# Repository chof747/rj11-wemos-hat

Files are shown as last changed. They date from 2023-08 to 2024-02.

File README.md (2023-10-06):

## rj11-wemos-hat
Stack-up board for the [wemos-mains-dev board](https://github.com/chof747/wemos-mains-dev) which includes 2 RJ11 connectors that can be connected via solder pads to the broken out pins of the wemos D1 mini on the main board.

The board has the form factor to be stacked up on the wemos mains dev board to enable mains powered wifi enabled 
microcontroller projects

### Elements

- 2 RJ11 Connectors
- Solder pads for all wemos pins (except 5V, 3V3 and GND)
- 2 1x2 connector pads exposing the data lines of the RJ11s
- 2 Jumpers to select the available 5V or 3V3 rail for the RJ11 connector
- A push button for the reset and a push button for the flash pin of the wemos D1 mini + pull-ups 
 
## Used Parts:

## Revision History:

- **v1.0**: Initial version (Produced: 19.08.2023; First Assembly: 06.10.2023)
- **v1.1**: Corrected RJ12 socket connector

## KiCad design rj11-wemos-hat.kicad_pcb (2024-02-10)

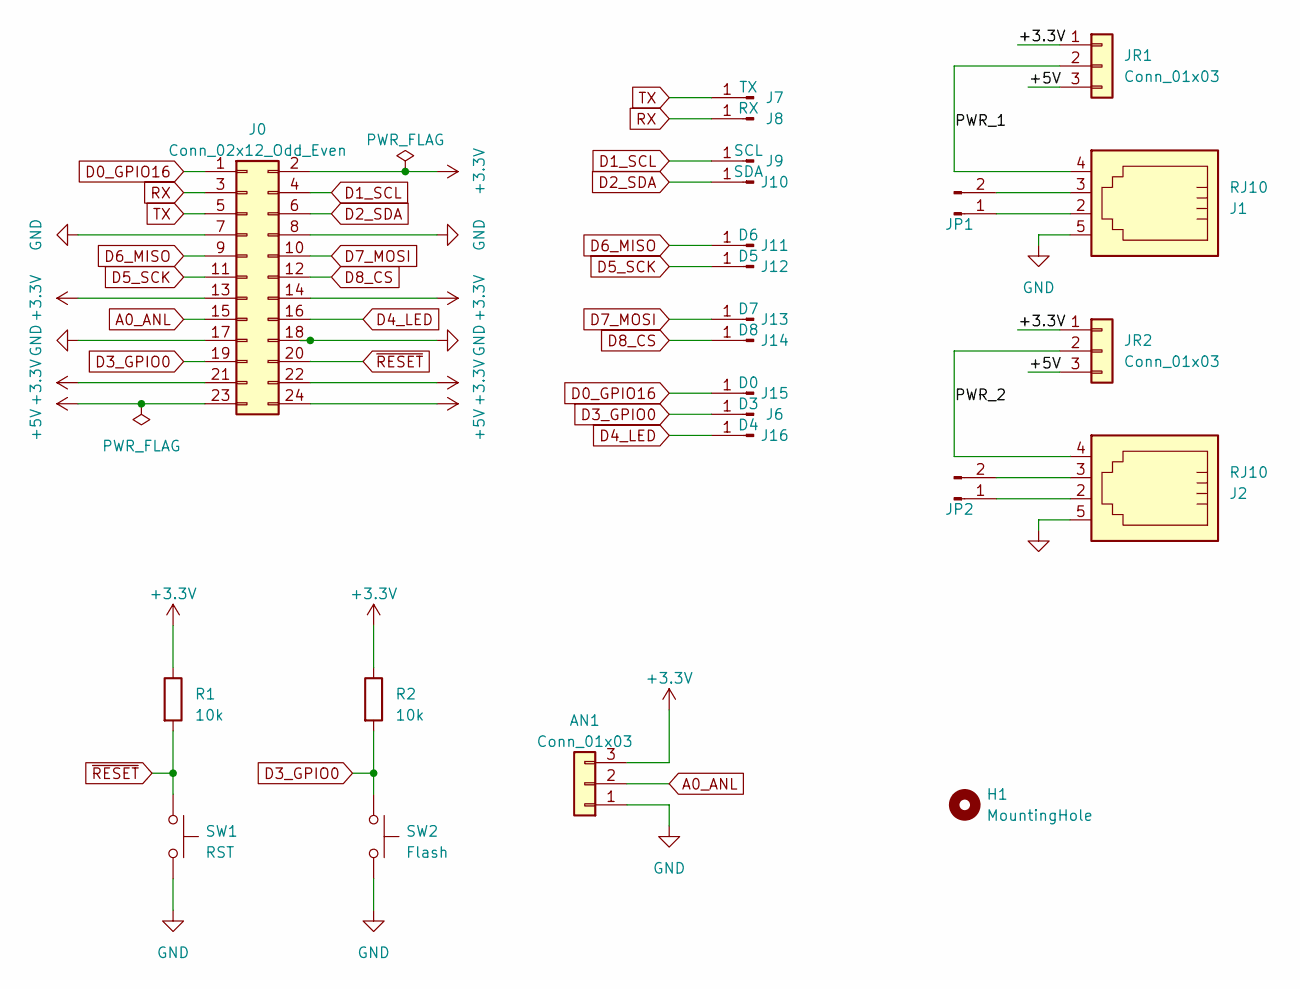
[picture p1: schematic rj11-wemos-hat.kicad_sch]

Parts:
AN1: Conn_01x03; PinHeader_1x03_P2.54mm_Vertical
H1: MountingHole; MountingHole_3mm
J0: Conn_02x12_Odd_Even; PinSocket_2x12_P2.54mm_Vertical
J1, J2: RJ10; RJ12_Amphenol_54601
J6: D3; Solder Pad 1x1 1.5x3
J7: TX; Solder Pad 1x1 1.5x3
J8: RX; Solder Pad 1x1 1.5x3
J9: SCL; Solder Pad 1x1 1.5x3
J10: SDA; Solder Pad 1x1 1.5x3
J11: D6; Solder Pad 1x1 1.5x3
J12: D5; Solder Pad 1x1 1.5x3
J13: D7; Solder Pad 1x1 1.5x3
J14: D8; Solder Pad 1x1 1.5x3
J15: D0; Solder Pad 1x1 1.5x3
J16: D4; Solder Pad 1x1 1.5x3
JP1, JP2: Solder Pad 1x2 1.5x3
JR1, JR2: Conn_01x03; PinHeader_1x03_P2.54mm_Vertical
R1, R2: 10k; R_0603_1608Metric_Pad0.98x0.95mm_HandSolder
SW1: RST; SW_PUSH_6mm
SW2: Flash; SW_PUSH_6mm

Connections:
+3.3V: AN1.3, J0.2, J0.13, J0.14, J0.21, J0.22, JR1.1, JR2.1, R1.1, R2.1; also elsewhere on the board
+5V: J0.23, J0.24, JR1.3, JR2.3; also elsewhere on the board
/PWR_1: J1.4, JR1.2
/PWR_2: J2.4, JR2.2; also elsewhere on the board
A0_ANL: AN1.2, J0.15
D0_GPIO16: J0.1, J15.1
D1_SCL: J0.4, J9.1
D2_SDA: J0.6, J10.1
D3_GPIO0: J0.19, J6.1, R2.2, SW2.1
D4_LED: J0.16, J16.1
D5_SCK: J0.11, J12.1
D6_MISO: J0.9, J11.1
D7_MOSI: J0.10, J13.1
D8_CS: J0.12, J14.1
GND: AN1.1, J0.7, J0.8, J0.17, J0.18, J1.5, J2.5, SW1.2, SW2.2
unnamed: J1.2, JP1.1
unnamed: J1.3, JP1.2
unnamed: J2.2, JP2.1
unnamed: J2.3, JP2.2
RX: J0.3, J8.1
TX: J0.5, J7.1
~RESET: J0.20, R1.2, SW1.1

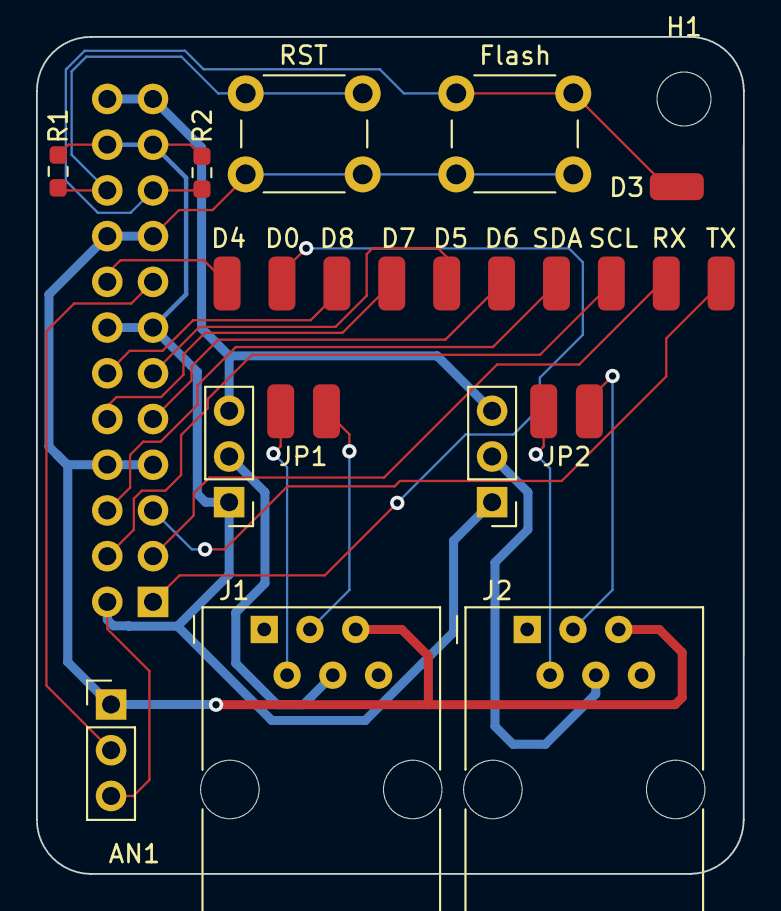
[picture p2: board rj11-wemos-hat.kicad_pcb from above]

Board: 2 copper layers, 39.3 x 46.5 mm, 24 parts (1 on the bottom side), 22 nets.

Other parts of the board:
locked: Conn_01x03; PinHeader_1x03_P2.54mm_Vertical

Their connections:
+3.3V: locked.1; also elsewhere on the board
+5V: locked.3; also elsewhere on the board
/PWR_2: locked.2; also elsewhere on the board

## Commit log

2023-08-04 First complete Draft
    [rj11-wemos-hat.kicad_pcb, rj11-wemos-hat.kicad_sch, template-project.kicad_sch]
2023-08-19 Initial version (Revision 1.0)
    [rj11-wemos-hat.kicad_pcb, rj11-wemos-hat.kicad_sch]
2023-09-15 corrected RJ12 socket Connector
    [rj11-wemos-hat.kicad_pcb, rj11-wemos-hat.kicad_sch]
2023-10-06 Format changes and first assembly
    [rj11-wemos-hat.kicad_pcb]
2024-02-10 added board outline
    [rj11-wemos-hat.kicad_pcb]
